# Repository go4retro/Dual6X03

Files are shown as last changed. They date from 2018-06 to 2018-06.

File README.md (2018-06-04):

# Dual 6X03 Adapter Schematic and Printed Circuit Board v1.0
This PCB will allow the use of two different 6X03 variants in a 6803-based system.  Only one CPU can be active at any time, and the CPU must be selected before boot.

## Theory
The 6X03 device can operate in modes 6801 configuration mode 2 or 3 only.  Essentially, Expanded Multiplexed mode with or without ROM.  At this moment, it is unclear how many of the 6X03 pins are tristated during RESET, so I took the safe approach of placing all known output lines (Address, Data, AS, E, R/W), and a few lines known to be outputs on the TANDY MC-10 (the first target of this PCB) to ensure operation.  If testing proves all lines to be in tristate or read state during RESET, I will simplify the schematic.

## License
Copyright (C) 2018  Jim Brain, RETRO Innovations

These files are free designs; you can redistribute them and/or modify
them under the terms of the Creative Commons Attribution-ShareAlike 
4.0 International License.

You should have received a copy of the license along with this
work. If not, see <http://creativecommons.org/licenses/by-sa/4.0/>.

These files are distributed in the hope that they will be useful,
but WITHOUT ANY WARRANTY; without even the implied warranty of
MERCHANTABILITY or FITNESS FOR A PARTICULAR PURPOSE.  See the
license for more details.

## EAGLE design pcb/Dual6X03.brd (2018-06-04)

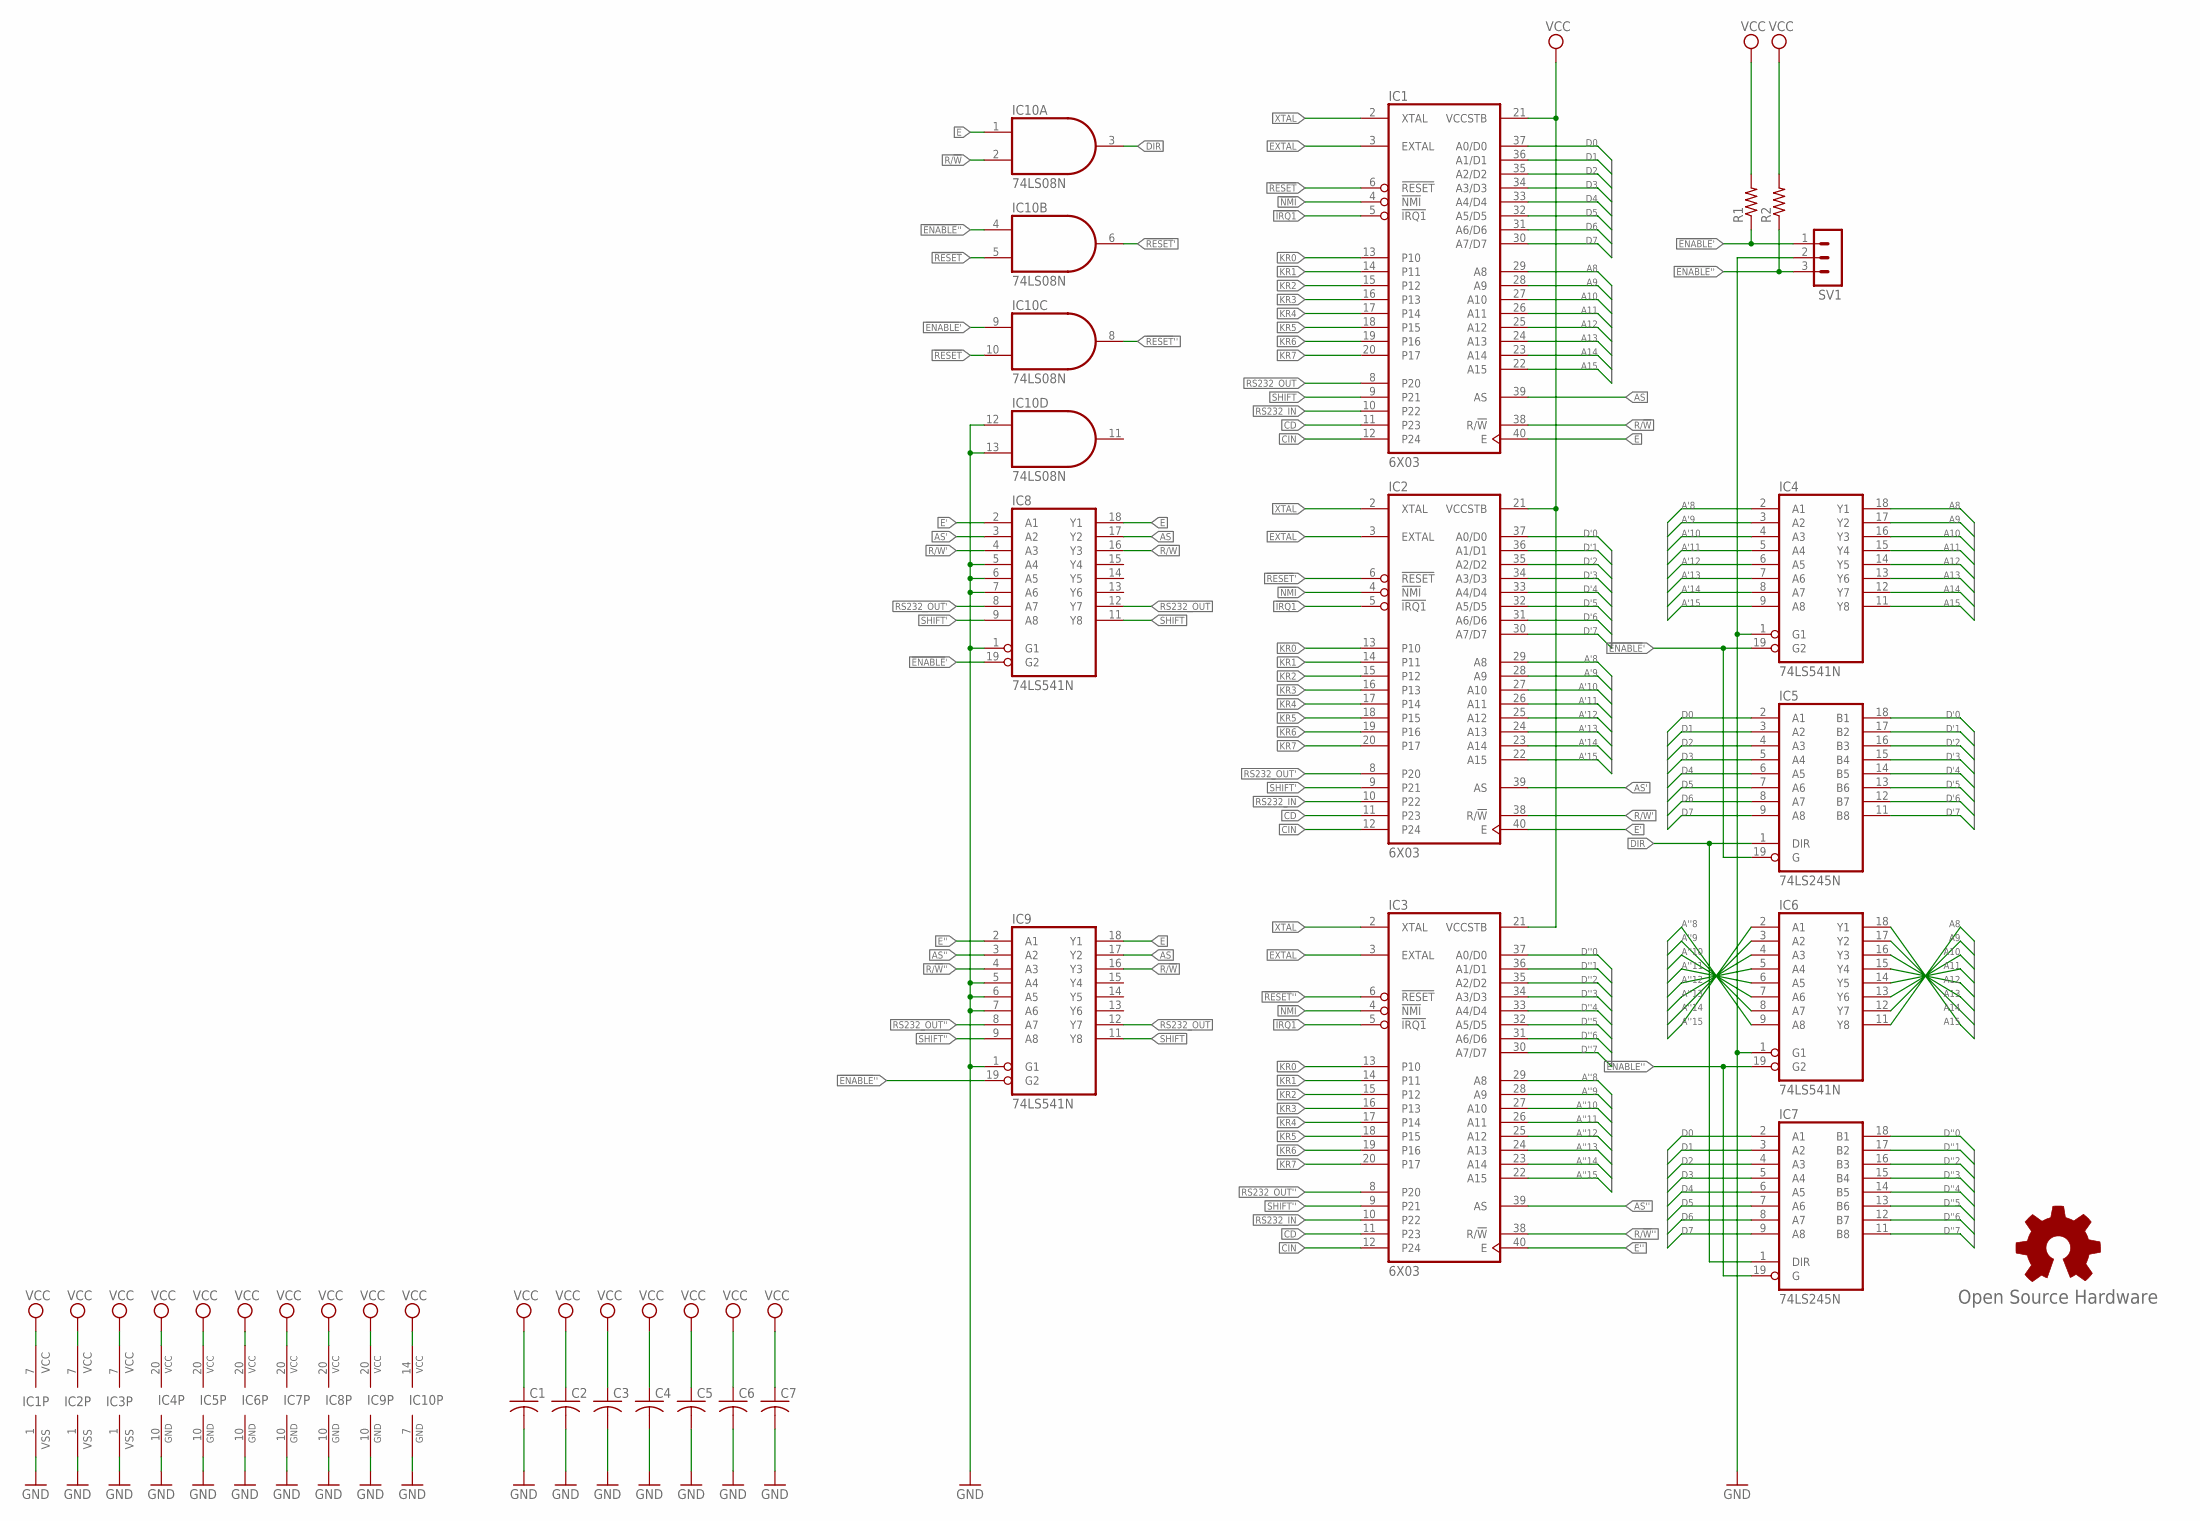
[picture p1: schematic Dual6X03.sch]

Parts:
C1, C2, C3, C4, C5, C6, C7: C-US025-025X050; C025-025X050
GOLD_ORB_SM1: Open Source Hardware; OSHW_8MM
IC1, IC2, IC3: 6X03; DIL40-ROUNDPAD
IC4, IC6, IC8, IC9: 74LS541N; DIL20
IC5, IC7: 74LS245N; DIL20
IC10: 74LS08N; DIL14
R1, R2: R-US_0204/2V; 0204V
SV1: MA03-1

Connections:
!ENABLE!': IC4.19 (G2), IC5.19 (G), IC8.19 (G2), IC10.9 (I0), R1.1, SV1.1
!ENABLE!'': IC6.19 (G2), IC7.19 (G), IC9.19 (G2), IC10.4 (I0), R2.1, SV1.3
!IRQ1: IC1.5 (!IRQ1), IC2.5 (!IRQ1), IC3.5 (!IRQ1)
!NMI: IC1.4 (!NMI), IC2.4 (!NMI), IC3.4 (!NMI)
!RESET: IC1.6 (!RESET), IC10.5 (I1), IC10.10 (I1)
!RESET!': IC2.6 (!RESET), IC10.6 (O)
!RESET!'': IC3.6 (!RESET), IC10.8 (O)
A8: IC1.29 (A8), IC4.18 (Y1), IC6.11 (Y8)
A9: IC1.28 (A9), IC4.17 (Y2), IC6.12 (Y7)
A10: IC1.27 (A10), IC4.16 (Y3), IC6.13 (Y6)
A11: IC1.26 (A11), IC4.15 (Y4), IC6.14 (Y5)
A12: IC1.25 (A12), IC4.14 (Y5), IC6.15 (Y4)
A13: IC1.24 (A13), IC4.13 (Y6), IC6.16 (Y3)
A14: IC1.23 (A14), IC4.12 (Y7), IC6.17 (Y2)
A15: IC1.22 (A15), IC4.11 (Y8), IC6.18 (Y1)
A'8: IC2.29 (A8), IC4.2 (A1)
A'9: IC2.28 (A9), IC4.3 (A2)
A'10: IC2.27 (A10), IC4.4 (A3)
A'11: IC2.26 (A11), IC4.5 (A4)
A'12: IC2.25 (A12), IC4.6 (A5)
A'13: IC2.24 (A13), IC4.7 (A6)
A'14: IC2.23 (A14), IC4.8 (A7)
A'15: IC2.22 (A15), IC4.9 (A8)
A''8: IC3.29 (A8), IC6.9 (A8)
A''9: IC3.28 (A9), IC6.8 (A7)
A''10: IC3.27 (A10), IC6.7 (A6)
A''11: IC3.26 (A11), IC6.6 (A5)
A''12: IC3.25 (A12), IC6.5 (A4)
A''13: IC3.24 (A13), IC6.4 (A3)
A''14: IC3.23 (A14), IC6.3 (A2)
A''15: IC3.22 (A15), IC6.2 (A1)
AS: IC1.39 (AS), IC8.17 (Y2), IC9.17 (Y2)
AS': IC2.39 (AS), IC8.3 (A2)
AS'': IC3.39 (AS), IC9.3 (A2)
CD: IC1.11 (P23), IC2.11 (P23), IC3.11 (P23)
CIN: IC1.12 (P24), IC2.12 (P24), IC3.12 (P24)
D0: IC1.37 (A0/D0), IC5.2 (A1), IC7.2 (A1)
D1: IC1.36 (A1/D1), IC5.3 (A2), IC7.3 (A2)
D2: IC1.35 (A2/D2), IC5.4 (A3), IC7.4 (A3)
D3: IC1.34 (A3/D3), IC5.5 (A4), IC7.5 (A4)
D4: IC1.33 (A4/D4), IC5.6 (A5), IC7.6 (A5)
D5: IC1.32 (A5/D5), IC5.7 (A6), IC7.7 (A6)
D6: IC1.31 (A6/D6), IC5.8 (A7), IC7.8 (A7)
D7: IC1.30 (A7/D7), IC5.9 (A8), IC7.9 (A8)
D'0: IC2.37 (A0/D0), IC5.18 (B1)
D'1: IC2.36 (A1/D1), IC5.17 (B2)
D'2: IC2.35 (A2/D2), IC5.16 (B3)
D'3: IC2.34 (A3/D3), IC5.15 (B4)
D'4: IC2.33 (A4/D4), IC5.14 (B5)
D'5: IC2.32 (A5/D5), IC5.13 (B6)
D'6: IC2.31 (A6/D6), IC5.12 (B7)
D'7: IC2.30 (A7/D7), IC5.11 (B8)
D''0: IC3.37 (A0/D0), IC7.18 (B1)
D''1: IC3.36 (A1/D1), IC7.17 (B2)
D''2: IC3.35 (A2/D2), IC7.16 (B3)
D''3: IC3.34 (A3/D3), IC7.15 (B4)
D''4: IC3.33 (A4/D4), IC7.14 (B5)
D''5: IC3.32 (A5/D5), IC7.13 (B6)
D''6: IC3.31 (A6/D6), IC7.12 (B7)
D''7: IC3.30 (A7/D7), IC7.11 (B8)
DIR: IC5.1 (DIR), IC7.1 (DIR), IC10.3 (O)
E: IC1.40 (E), IC8.18 (Y1), IC9.18 (Y1), IC10.1 (I0)
E': IC2.40 (E), IC8.2 (A1)
E'': IC3.40 (E), IC9.2 (A1)
EXTAL: IC1.3 (EXTAL), IC2.3 (EXTAL), IC3.3 (EXTAL)
GND: C1.2, C2.2, C3.2, C4.2, C5.2, C6.2, C7.2, IC1.1 (VSS), IC2.1 (VSS), IC3.1 (VSS), IC4.1 (G1), IC4.10 (GND), IC5.10 (GND), IC6.1 (G1), IC6.10 (GND), IC7.10 (GND), IC8.1 (G1), IC8.5 (A4), IC8.6 (A5), IC8.7 (A6), IC8.10 (GND), IC9.1 (G1), IC9.5 (A4), IC9.6 (A5), IC9.7 (A6), IC9.10 (GND), IC10.7 (GND), IC10.12 (I0), IC10.13 (I1), SV1.2
KR0: IC1.13 (P10), IC2.13 (P10), IC3.13 (P10)
KR1: IC1.14 (P11), IC2.14 (P11), IC3.14 (P11)
KR2: IC1.15 (P12), IC2.15 (P12), IC3.15 (P12)
KR3: IC1.16 (P13), IC2.16 (P13), IC3.16 (P13)
KR4: IC1.17 (P14), IC2.17 (P14), IC3.17 (P14)
KR5: IC1.18 (P15), IC2.18 (P15), IC3.18 (P15)
KR6: IC1.19 (P16), IC2.19 (P16), IC3.19 (P16)
KR7: IC1.20 (P17), IC2.20 (P17), IC3.20 (P17)
R/!W: IC1.38 (R/!W), IC8.16 (Y3), IC9.16 (Y3), IC10.2 (I1)
R/!W!': IC2.38 (R/!W), IC8.4 (A3)
R/!W!'': IC3.38 (R/!W), IC9.4 (A3)
RS232_IN: IC1.10 (P22), IC2.10 (P22), IC3.10 (P22)
RS232_OUT: IC1.8 (P20), IC8.12 (Y7), IC9.12 (Y7)
RS232_OUT': IC2.8 (P20), IC8.8 (A7)
RS232_OUT'': IC3.8 (P20), IC9.8 (A7)
SHIFT: IC1.9 (P21), IC8.11 (Y8), IC9.11 (Y8)
SHIFT': IC2.9 (P21), IC8.9 (A8)
SHIFT'': IC3.9 (P21), IC9.9 (A8)
VCC: C1.1, C2.1, C3.1, C4.1, C5.1, C6.1, C7.1, IC1.7 (VCC), IC1.21 (VCCSTB), IC2.7 (VCC), IC2.21 (VCCSTB), IC3.7 (VCC), IC3.21 (VCCSTB), IC4.20 (VCC), IC5.20 (VCC), IC6.20 (VCC), IC7.20 (VCC), IC8.20 (VCC), IC9.20 (VCC), IC10.14 (VCC), R1.2, R2.2
XTAL: IC1.2 (XTAL), IC2.2 (XTAL), IC3.2 (XTAL)

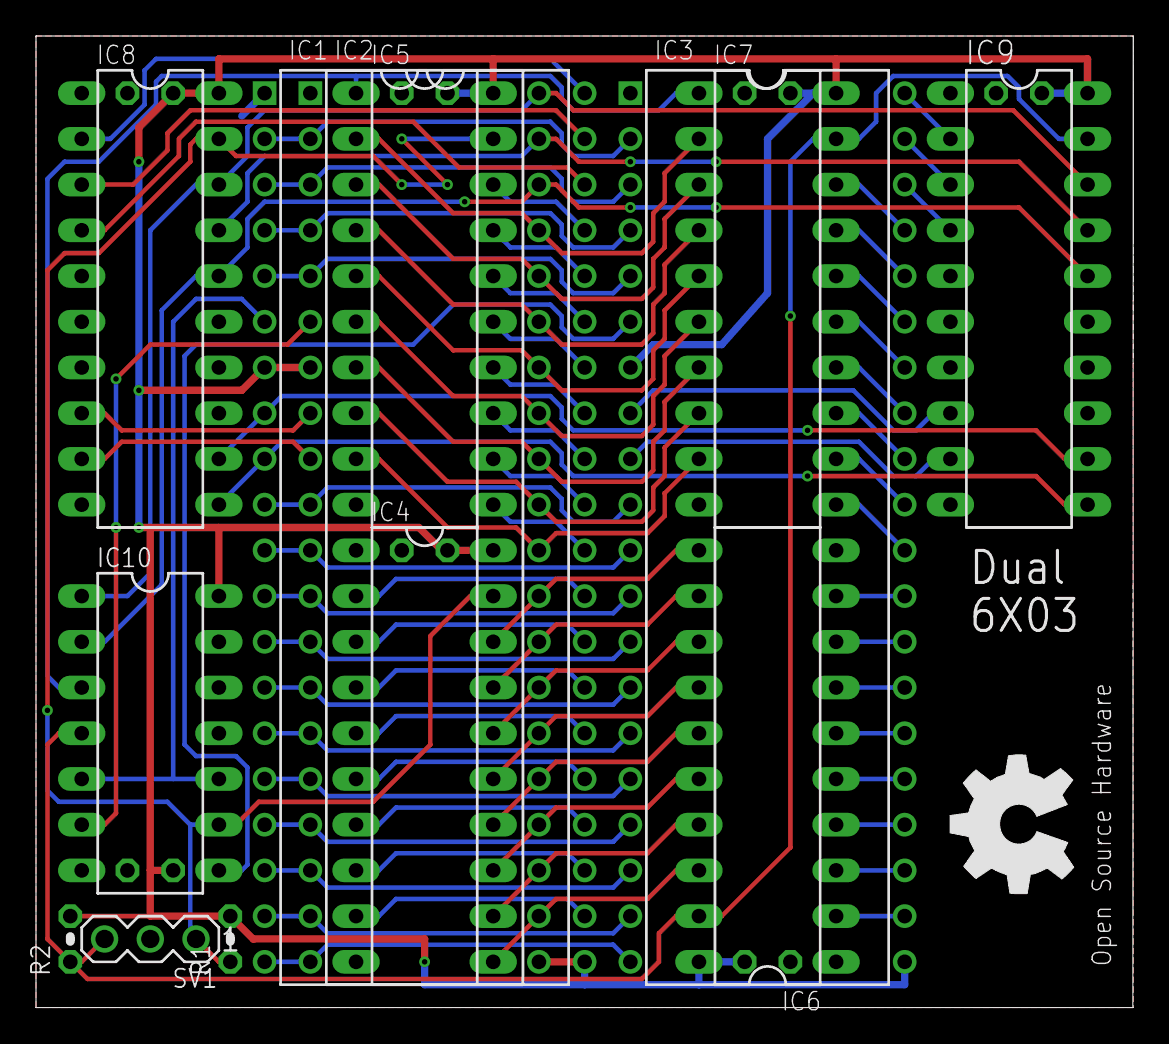
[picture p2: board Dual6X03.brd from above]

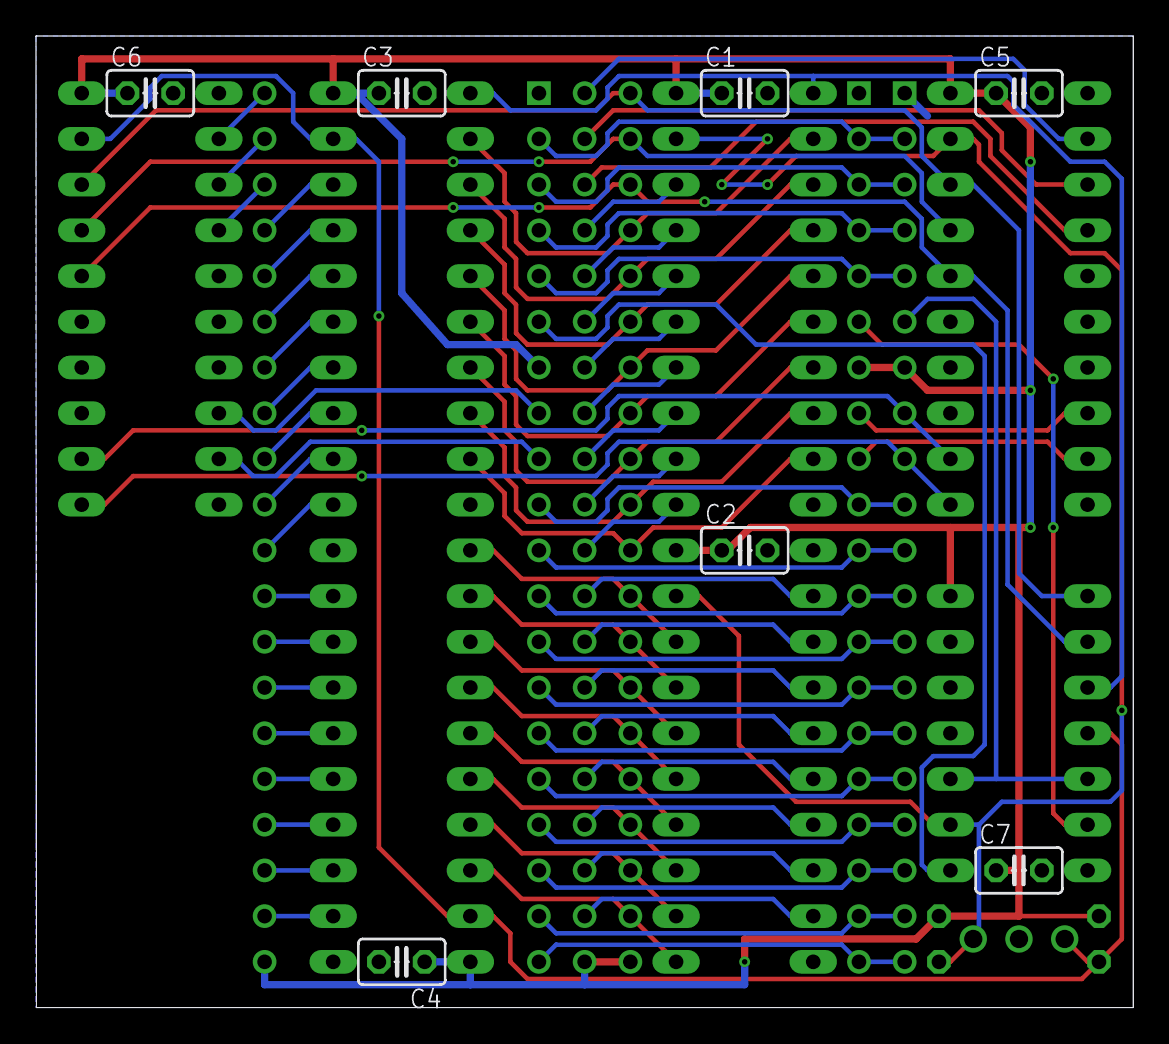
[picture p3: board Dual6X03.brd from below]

Board: 2 copper layers, 61.0 x 54.0 mm, 21 parts (7 on the bottom side), 86 nets.
